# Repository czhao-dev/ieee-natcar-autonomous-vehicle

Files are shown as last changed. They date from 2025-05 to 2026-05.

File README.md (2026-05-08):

# IEEE NATCAR Autonomous Race Car

An autonomous electric race car built for the IEEE NATCAR competition. The project combines embedded firmware, custom PCB design, optical sensing, inductive sensing, motor control, and real-time steering control on a modified RC car platform.

The vehicle follows a track using a 128-pixel line-scan camera and explored sensor fusion with three inductive pickups. The final firmware reads the camera, estimates the track line position, applies PD-style steering control, and adjusts motor PWM based on how aggressively the car needs to turn.

## Project Highlights

- Built and tuned an autonomous race car for IEEE NATCAR
- Implemented real-time line following in Arduino-style C/C++
- Used a TSL1401-style 128-pixel line-scan camera for track detection
- Designed around a custom Teensy 3.1-compatible controller PCB
- Integrated left, center, and right inductive sensors through analog front-end circuitry
- Controlled steering with a servo and propulsion with dual PWM motor outputs
- Iterated through multiple firmware versions during testing and tuning

## How It Works

```mermaid
flowchart LR
    Camera["Line-scan camera"] --> Firmware["Teensy / Arduino firmware"]
    Inductors["Inductive sensors"] --> AFE["Analog front end"]
    AFE --> Firmware
    Firmware --> Steering["Servo steering"]
    Firmware --> Motors["PWM motor drive"]
    Battery["Battery"] --> Power["5V / 3.3V regulation"]
    Power --> Firmware
    Power --> AFE
```

At runtime, the controller:

1. Clocks the line-scan camera and reads 128 analog pixel values.
2. Finds the strongest rising and falling edges in the camera data.
3. Estimates the line midpoint relative to a calibrated camera center.
4. Converts the line offset into a steering angle.
5. Reduces speed during sharper turns.
6. Writes servo and motor PWM commands.

More detail is available in [System Overview](docs/system-overview.md) and [Control Algorithm](docs/control-algorithm.md).

## Repository Structure

```text
NATCAR/
  README.md
  firmware/
    natcar_final/
      natcar_final.ino
    archive/
      natcar_v1.1.ino
      natcar_v1.2.ino
      natcar_v1.3.ino
      natcar_v1.4.ino
      natcar_v1.5.ino
      natcar_v1.6.ino
      natcar_v1.8.ino
      natcar_v1.9.ino
  hardware/
    Natcar 1.01.sch
    Natcar 1.01.brd
  docs/
    system-overview.md
    control-algorithm.md
    hardware.md
    calibration.md
    firmware-history.md
  data/
    inductor_measurement.xlsx
    inductor scaling.xlsx
  references/
    28317-TSL1401-DB-Manual.pdf
  images/
    control-loop.png
    hardware-pin-map.png
    system-architecture.png
```

## Documentation

- [System Overview](docs/system-overview.md): full vehicle architecture and subsystem summary
- [Control Algorithm](docs/control-algorithm.md): camera processing, steering control, speed control, and earlier sensor-fusion logic
- [Hardware](docs/hardware.md): PCB, major components, power, motor drive, and pin mapping
- [Calibration](docs/calibration.md): inductor measurement and scaling notes
- [Firmware History](docs/firmware-history.md): what changed across the archived firmware versions

## Hardware Summary

| Area | Description |
| --- | --- |
| Chassis | Custom-modified RC car platform |
| Controller | Teensy 3.1-compatible Arduino-style firmware target |
| Optical sensor | 128-pixel line-scan camera |
| Inductive sensors | Left, center, and right pickups for guide detection |
| Actuators | Steering servo and left/right motor outputs |
| PCB | Custom Eagle schematic and board files |
| Power | Battery input with onboard 5V and 3.3V regulation |

## Firmware Summary

The final sketch lives at:

```text
firmware/natcar_final/natcar_final.ino
```

Key control constants in the final firmware:

| Parameter | Value | Purpose |
| --- | ---: | --- |
| `TOP_SPEED_PWM` | `100` | Base motor PWM target |
| `STEERING_KP` | `0.6` | Steering proportional gain |
| `STEERING_KD` | `0.6` | Steering derivative gain |
| `CAMERA_CENTER_PIXEL` | `58` | Calibrated camera center |
| `SERVO_CENTER` | `45` | Servo center |
| `SERVO_RANGE` | `25` | Servo command clamp |

Archived sketches are kept in `firmware/archive/` to show the development process, including earlier camera-plus-inductor fusion attempts.

## Development Notes

This project was built collaboratively by a four-person team. Work included hardware wiring, PCB design, sensor integration, real-time control firmware, serial debugging, calibration, and track testing.

The repository is organized as a showcase of the complete embedded design cycle rather than a packaged library. The hardware files require Eagle-compatible tooling, and the final firmware is intended for an Arduino/Teensyduino-style environment with the Servo library available.

## License

This project is licensed under the Apache License 2.0. See [LICENSE](LICENSE) for details.

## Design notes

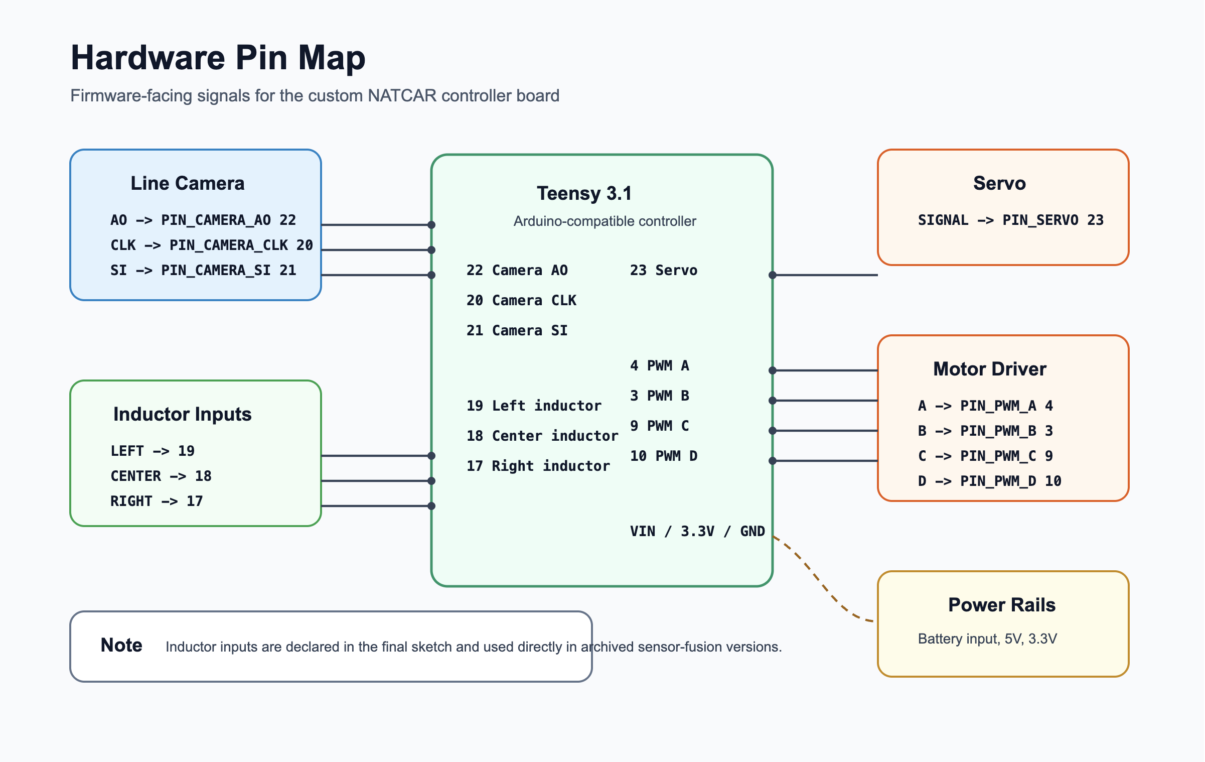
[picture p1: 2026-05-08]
images/hardware-pin-map.png

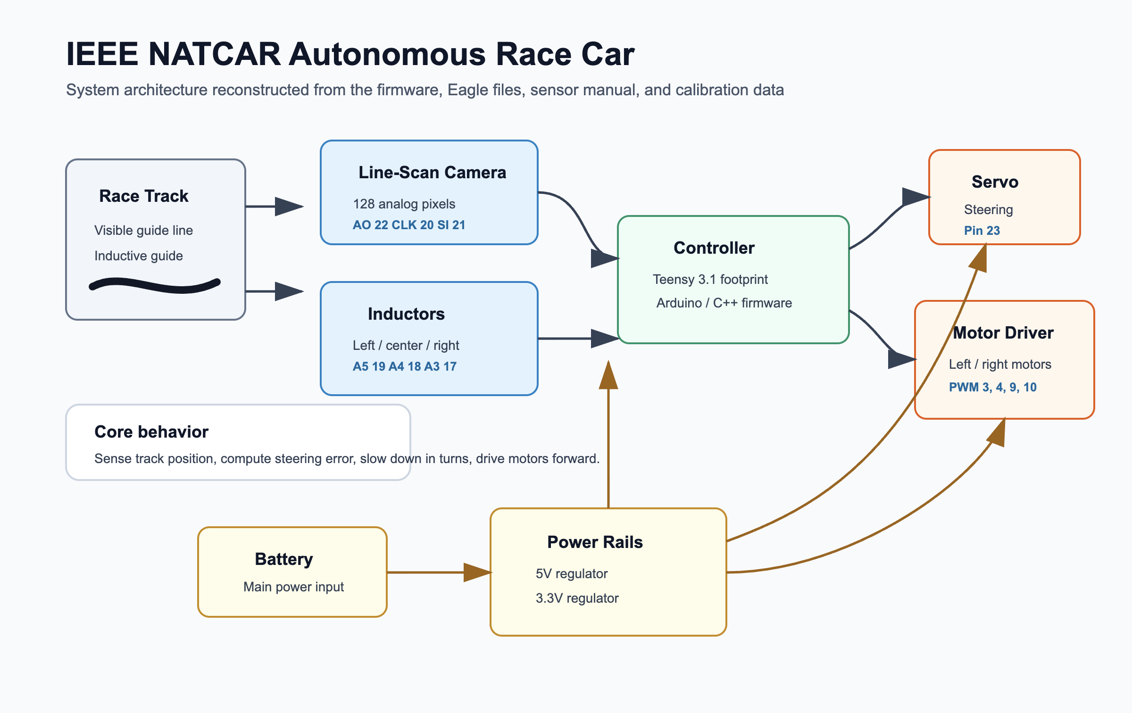
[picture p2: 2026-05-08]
images/system-architecture.png

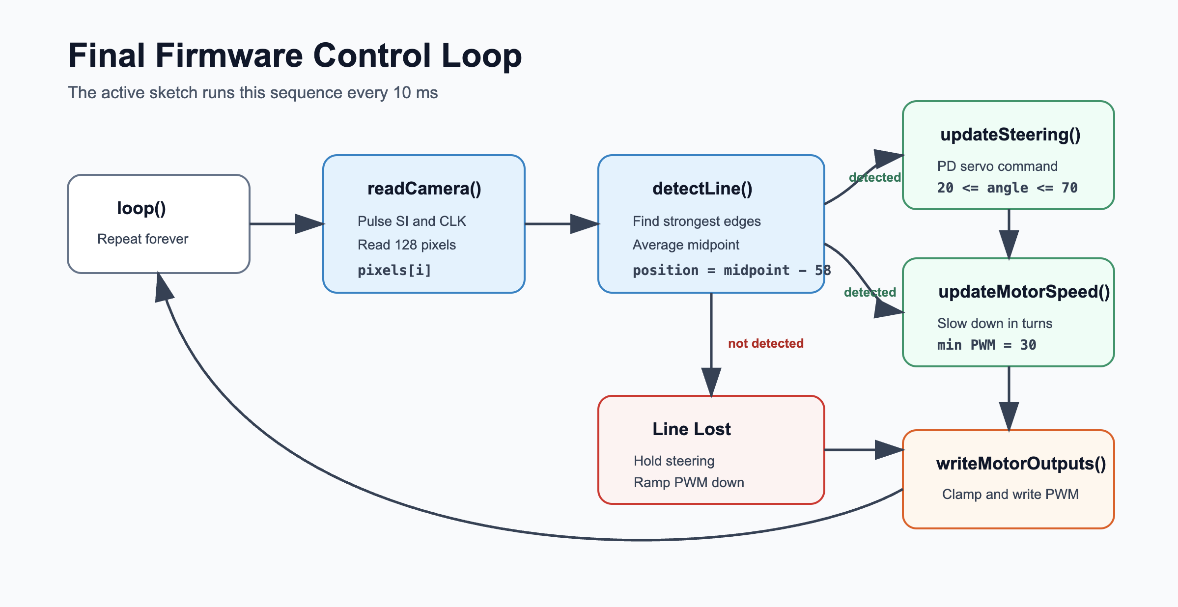
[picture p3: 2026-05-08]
images/control-loop.png

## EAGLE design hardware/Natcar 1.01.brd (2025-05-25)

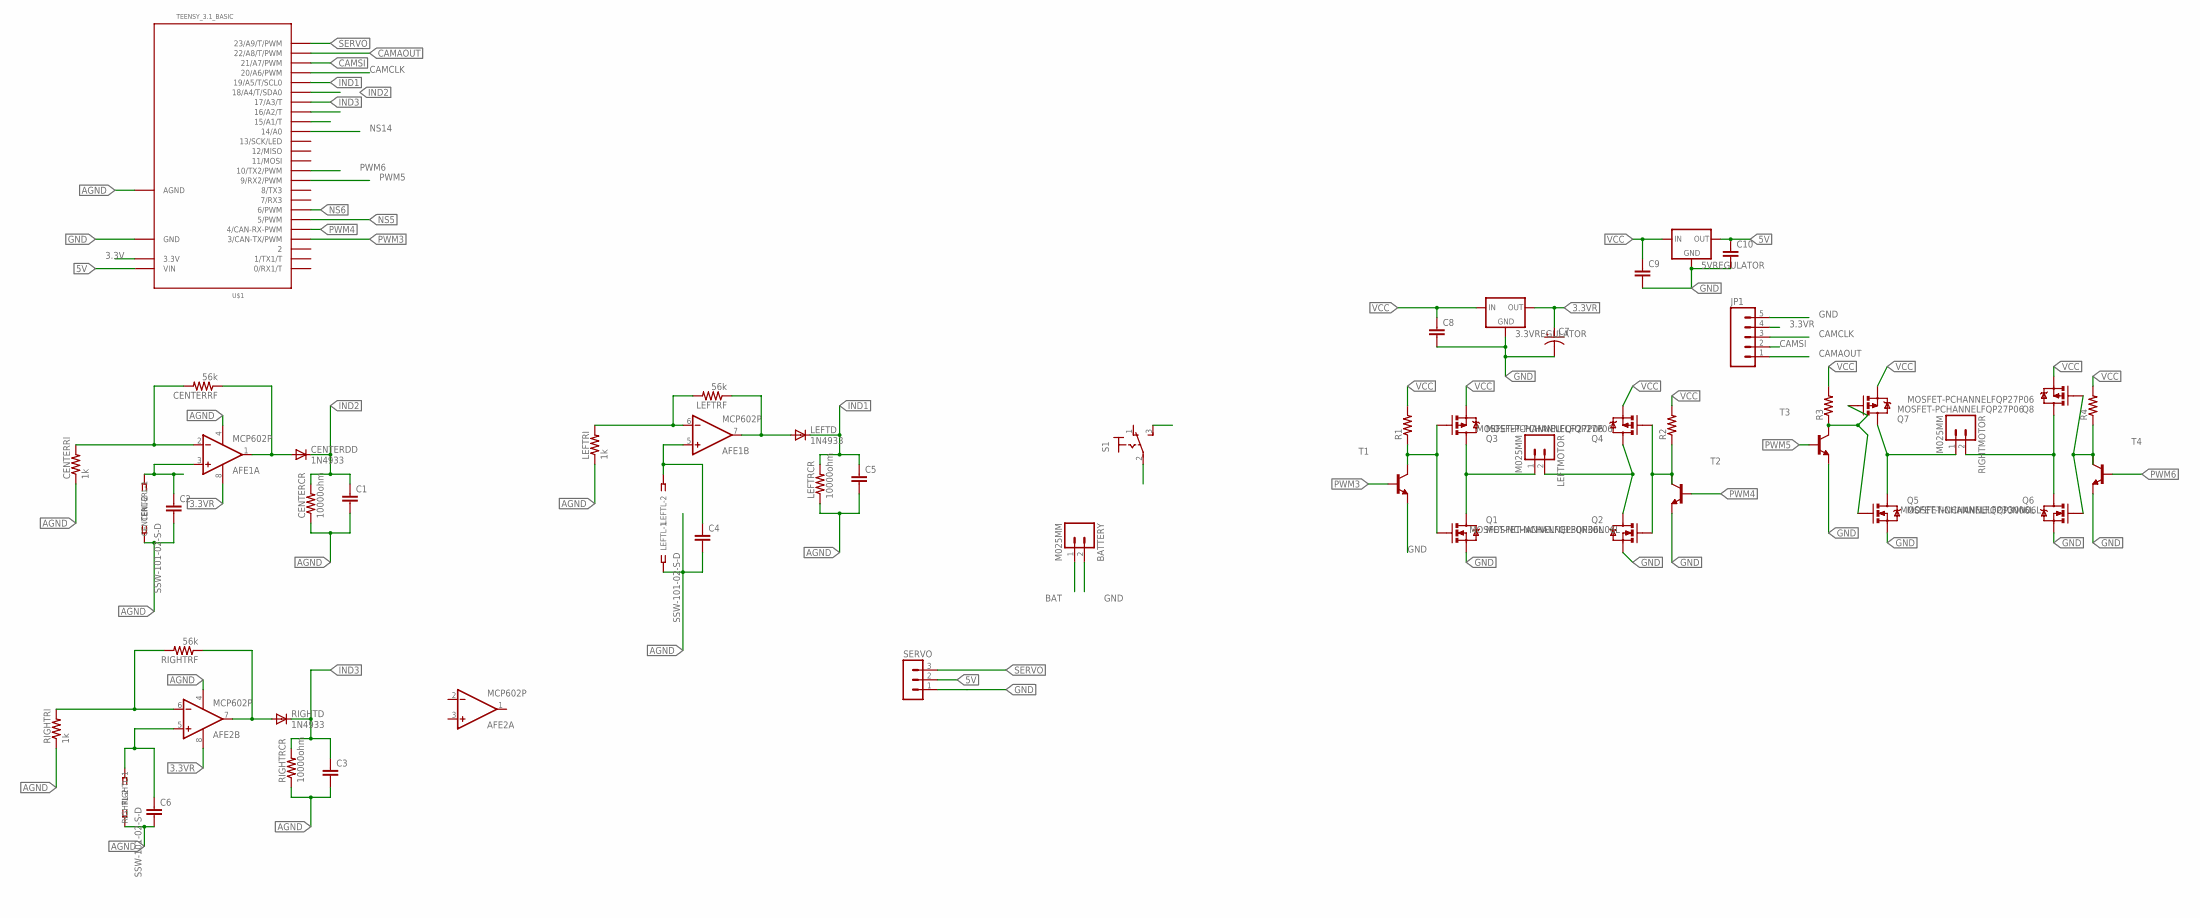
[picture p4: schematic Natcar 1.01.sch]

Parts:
3.3VREGULATOR, 5VREGULATOR: V_REG_78XXSINK; TO220-IGO
AFE1, AFE2: MCP602P; DIL08
BATTERY: M025MM; SCREWTERMINAL-5MM-2
C1, C2, C3, C4, C5, C6: CAPEZ; CAP-PTH-SMALLEZ
C7: CAP_POLPTH2; CPOL-RADIAL-10UF-25V
C8, C9, C10: CAPPTH2; CAP-PTH-SMALL2
CENTERCR: 10000ohm; 0204/5
CENTERDD: 1N4933; DO41-10
CENTERL: SSW-101-02-S-D
CENTERRF: 56k; 0204/5
CENTERRI: 1k; 0204/5
JP1: M05PTH; 1X05
LEFTD: 1N4933; DO41-10
LEFTL: SSW-101-02-S-D
LEFTMOTOR: M025MM; SCREWTERMINAL-5MM-2
LEFTRCR: 10000ohm; 0204/5
LEFTRF: 56k; 0204/5
LEFTRI: 1k; 0204/5
Q1, Q2, Q5, Q6: MOSFET-NCHANNELFQP30N06L; TO220V
Q3, Q4, Q7, Q8: MOSFET-PCHANNELFQP27P06; TO220V
R1, R2, R3, R4: R-US_0204/5; 0204/5
RIGHTD: 1N4933; DO41-10
RIGHTL: SSW-101-02-S-D
RIGHTMOTOR: M025MM; SCREWTERMINAL-5MM-2
RIGHTRCR: 10000ohm; 0204/5
RIGHTRF: 56k; 0204/5
RIGHTRI: 1k; 0204/5
S1: 320-916
SERVO: MA03-1
T1, T2, T3, T4: -NPN-TO92-EBC; TO92-EBC
U$1: TEENSY_3.1_BASIC

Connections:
3.3V: U$1.3.3V
3.3VR: 3.3VREGULATOR.OUT, AFE1.8 (V+), AFE2.8 (V+), C7.1 (+), JP1.4
5V: 5VREGULATOR.OUT, C10.1, SERVO.2, U$1.VIN
AGND: AFE1.4 (V-), AFE2.4 (V-), C1.2, C2.2, C3.2, C4.2, C5.2, C6.2, CENTERCR.1, CENTERL.1, CENTERRI.1, LEFTL.1, LEFTRCR.1, LEFTRI.1, RIGHTL.1, RIGHTRCR.1, RIGHTRI.1, U$1.AGND
BAT: BATTERY.1, S1.3 (S)
CAMAOUT: JP1.1, U$1.22/A8 (22/A8/T/PWM)
CAMCLK: JP1.3, U$1.20/A6 (20/A6/PWM)
CAMSI: JP1.2, U$1.21/A7 (21/A7/PWM)
GND: 3.3VREGULATOR.GND, 5VREGULATOR.GND, BATTERY.2, C7.2 (-), C8.2, C9.2, C10.2, JP1.5, Q1.3 (S), Q2.3 (S), Q5.3 (S), Q6.3 (S), SERVO.1, T1.E, T2.E, T3.E, T4.E, U$1.GND
IND1: C5.1, LEFTD.C, LEFTRCR.2, U$1.19/A5 (19/A5/T/SCL0)
IND2: C1.1, CENTERCR.2, CENTERDD.C, U$1.18/A4 (18/A4/T/SDA0)
IND3: C3.1, RIGHTD.C, RIGHTRCR.2, U$1.17/A3 (17/A3/T)
unnamed: LEFTMOTOR.2, Q2.2 (D), Q4.2 (D)
unnamed: Q2.1 (G), Q4.1 (G), R2.1, T2.C
unnamed: Q5.2 (D), Q7.2 (D), RIGHTMOTOR.1
unnamed: Q6.2 (D), Q8.2 (D), RIGHTMOTOR.2
unnamed: Q1.1 (G), Q3.1 (G), R1.1, T1.C
unnamed: Q5.1 (G), Q7.1 (G), R3.1, T3.C
unnamed: Q6.1 (G), Q8.1 (G), R4.1, T4.C
unnamed: LEFTMOTOR.1, Q1.2 (D), Q3.2 (D)
unnamed: AFE2.6 (-IN), RIGHTRF.2, RIGHTRI.2
unnamed: AFE2.7 (OUT), RIGHTD.A, RIGHTRF.1
unnamed: AFE1.2 (-IN), CENTERRF.2, CENTERRI.2
unnamed: AFE1.3 (+IN), C2.1, CENTERL.2
unnamed: AFE2.5 (+IN), C6.1, RIGHTL.2
unnamed: AFE1.1 (OUT), CENTERDD.A, CENTERRF.1
unnamed: AFE1.7 (OUT), LEFTD.A, LEFTRF.1
unnamed: AFE1.5 (+IN), C4.1, LEFTL.2
unnamed: AFE1.6 (-IN), LEFTRF.2, LEFTRI.2
NS5: U$1.5 (5/PWM)
NS6: U$1.6 (6/PWM)
NS14: U$1.14/A0
PWM3: T1.B, U$1.3 (3/CAN-TX/PWM)
PWM4: T2.B, U$1.4 (4/CAN-RX-PWM)
PWM5: T3.B, U$1.9 (9/RX2/PWM)
PWM6: T4.B, U$1.10 (10/TX2/PWM)
SERVO: SERVO.3, U$1.23/A9 (23/A9/T/PWM)
VCC: 3.3VREGULATOR.IN, 5VREGULATOR.IN, C8.1, C9.1, Q3.3 (S), Q4.3 (S), Q7.3 (S), Q8.3 (S), R1.2, R2.2, R3.2, R4.2, S1.2

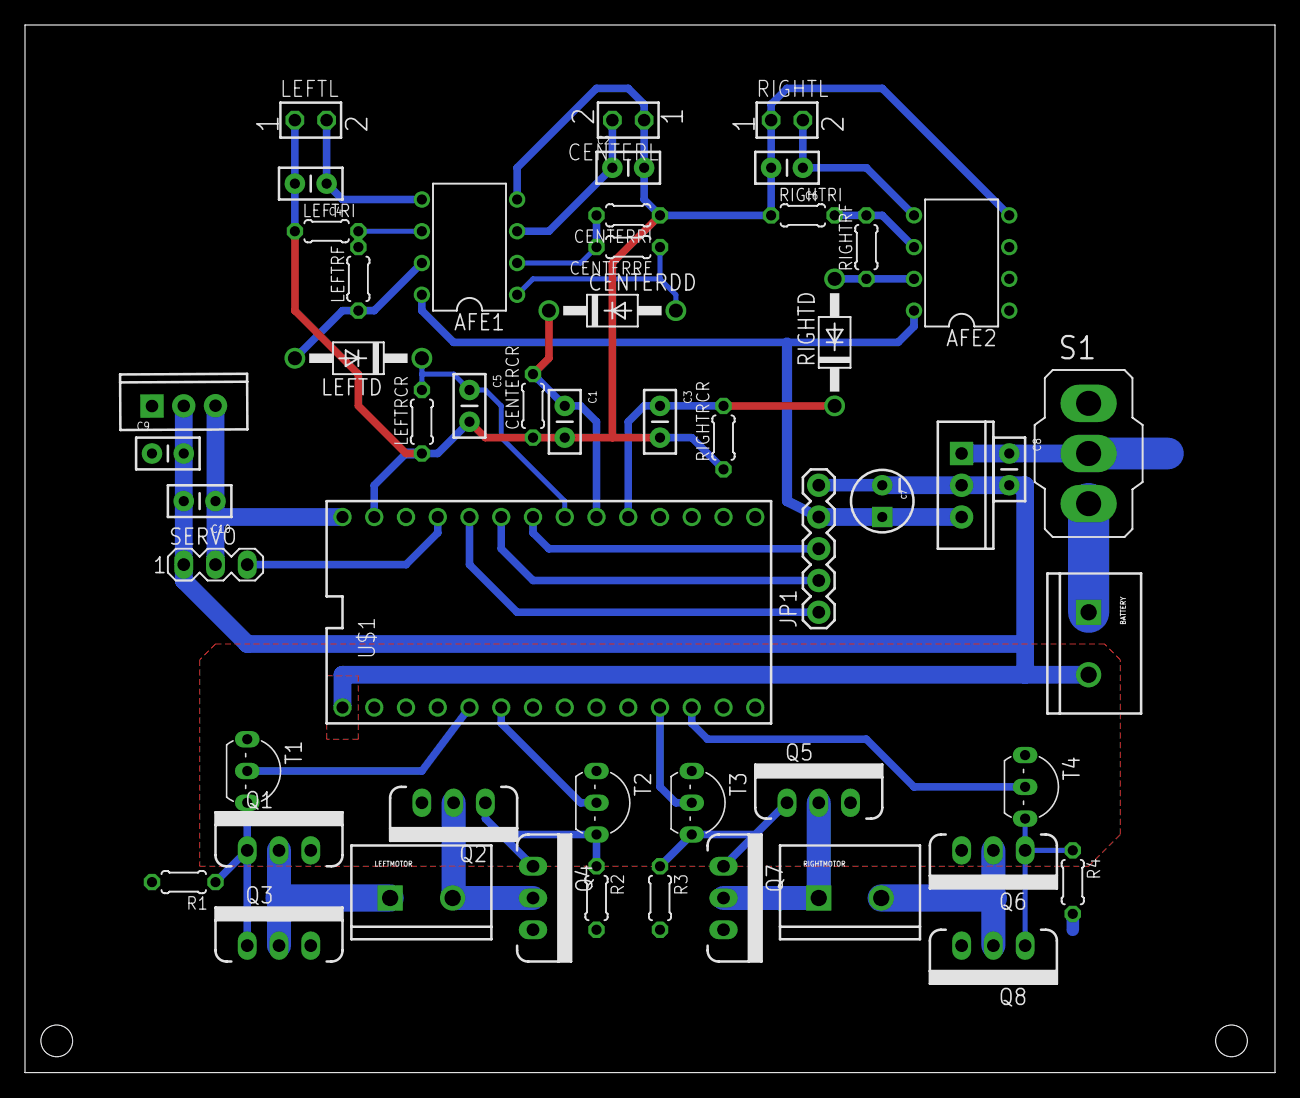
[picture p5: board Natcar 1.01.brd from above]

Board: 2 copper layers, 100.0 x 83.8 mm, 52 parts (0 on the bottom side), 34 nets.

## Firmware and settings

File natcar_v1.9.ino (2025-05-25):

#include <Servo.h>
Servo myservo;

//Pin defination
int pin_AO = 22;
int pin_CLK = 20;
int pin_SI = 21;
int pin_servo = 23;
int left_inductor_pin = 19;
int center_inductor_pin = 18;
int right_inductor_pin = 17;
int PWM_A = 4;
int PWM_B = 3;
int PWM_C = 9;
int PWM_D = 10;
int delayt = 10;


//Speed Parameters
const int topSpeed = 100;

//Steering Parameters
float kp_s = 1;//speed Kp
float kd_s = 0;//speed Kd

float kp_a = 0.6;//angle Kp 
float kd_a = 0.6;//angle Kd
const int midPosition = 45;
const int range = 25;

float angle;
float prev_angle = 45;

float left_PWM;
float right_PWM;
float prev_left_PWM;
float prev_right_PWM;

//Cam setting
int CAM_state;
int pixels[128];
int CAMmid = 58;
int CAM_position;
int PRE_CAM_position;

void setup()
{
  pinMode(PWM_A, OUTPUT);
  pinMode(PWM_B, OUTPUT);
  pinMode(pin_CLK, OUTPUT);
  pinMode(pin_SI,OUTPUT);
  pinMode(pin_AO, INPUT);
  pinMode(pin_servo, OUTPUT);
  Serial.begin(9600);
  myservo.attach(pin_servo);
  left_PWM = 0;
  right_PWM = 0;
}

void loop()
{
  //initializeCam();
  readCam();
  CamPos();
  ServoControl();
  MotorControl();
  delay(delayt);
  
  //printCAM();
  //printControl();
  //Serial.print("\n");
}

/*void printControl()
{
  
  Serial.print("camstate: | ");
  Serial.print(CAM_state);
}*/


/*void printCAM()
{
  Serial.print(" cam | ");
  Serial.print(CAM_state);
  Serial.print("|");
  Serial.print(CAM_position);
 
  //Serial.print(PRE_CAM_positionl);
}*/

void MotorControl()
{  
  prev_left_PWM = left_PWM;
  prev_right_PWM = right_PWM;
  if(CAM_state == 0)
  {
    if(left_PWM >30)
    left_PWM--;
    else
    left_PWM = 30;
    
    if(right_PWM > 30)
    right_PWM --;
    else
    right_PWM = 30;
  }
  else
  {
    left_PWM = topSpeed - abs(CAM_position)*1.8;//deceleration here!!!!!! 
    left_PWM = left_PWM*kp_s + kd_s*(left_PWM - prev_left_PWM); 
    
    if(left_PWM < 30) left_PWM = 30;
    
    right_PWM = left_PWM;
  }
  //Serial.print(" L |");
  //Serial.print(left);
  //Serial.print(" R |");
  //Serial.print(right);
  
  
  analogWrite(PWM_A, 0);
  analogWrite(PWM_B, left_PWM);
  analogWrite(PWM_C, 0);
  analogWrite(PWM_D, right_PWM);
}

void ServoControl()
{
  prev_angle = angle;
  if(CAM_state == 0)
  {
    angle = angle;  
  }
  else angle = 45 - CAM_position * kp_a - (CAM_position - PRE_CAM_position)*kd_a;
  //angle = kp_a*angle + kd_a * (angle - prev_angle);
  angle = max(midPosition-range, angle);
  angle = min(midPosition+range, angle);
  
  //Serial.print(" angle |  ");
  //Serial.print(angle);
  
  myservo.write(int(angle));
}

void initializeCam()
{
  digitalWrite(pin_SI, HIGH);
  digitalWrite(pin_CLK, HIGH);
  digitalWrite(pin_SI, LOW);
  digitalWrite(pin_CLK, LOW);
}


void readCam()
{
  initializeCam();
  for(int i = 0; i < 128; i++)
  {
    digitalWrite(pin_CLK, HIGH);
    pixels[i] = analogRead(pin_AO);
    digitalWrite(pin_CLK, LOW);
    //Serial.print(pixels[i]/70);
    //Serial.print(" ");   
  }
  //Serial.print("\n");
}

void CamPos()
{
  int head, tail, midPoint, diff;
  int maxDiff = 0;
  int minDiff = 0;
  
  for(int i = 0; i < 127; i++)
  {
    diff = pixels[i+ 1] - pixels[i];

    if (diff < minDiff)
    {
      tail = i;
      minDiff = diff;
    }
    
    if (diff > maxDiff)
    {
      head = i;
      maxDiff = diff;
    }
  }
    midPoint = (head + tail)/2;
    
    if(pixels[midPoint] > 200)
    {
      CAM_state = 1;
      PRE_CAM_position = CAM_position;
      CAM_position = midPoint-CAMmid;
    }

    
}

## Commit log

2025-05-25 Add arduino files for line detection algorithms
    [Natcar 1.01.brd, Natcar 1.01.sch]
2026-05-08 Move Natcar 1.01.brd to hardware/Natcar 1.01.brd
    [Natcar 1.01.brd]
2026-05-08 Add schematic images

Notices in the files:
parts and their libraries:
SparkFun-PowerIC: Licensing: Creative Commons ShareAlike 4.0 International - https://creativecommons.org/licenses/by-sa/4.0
